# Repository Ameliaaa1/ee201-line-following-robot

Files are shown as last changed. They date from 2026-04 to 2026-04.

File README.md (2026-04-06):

# EE201 Line Following Robot

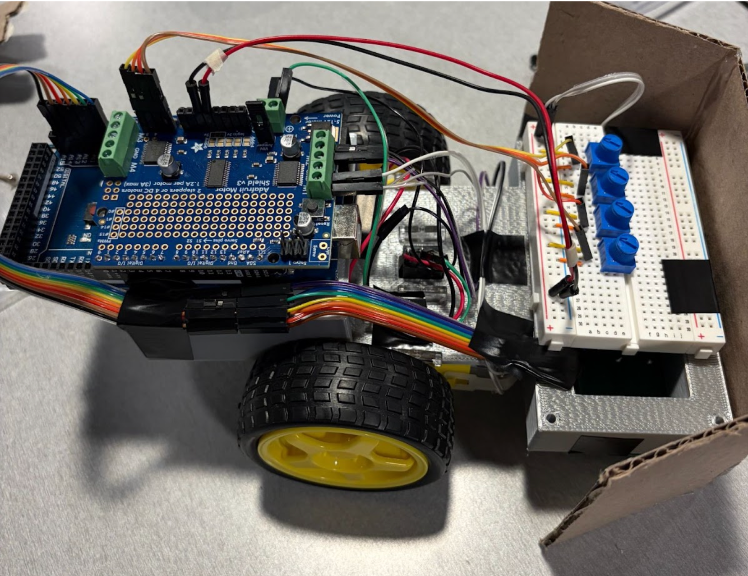
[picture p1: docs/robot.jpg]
Robot


A line-following robot built using Arduino, a custom sensor array, and PID control. This project was developed for EE 201 and focuses on integrating hardware design, embedded systems, and real-time control.

## Overview

This robot detects and follows a black line on a white surface using a photoresistor sensor array. Sensor readings are processed by an Arduino Mega, which adjusts motor speeds using a PID control algorithm to maintain alignment with the track.

## Features

- Arduino Mega + Adafruit Motor Shield
- 7-photoresistor sensor array with LED illumination
- Custom PCB design
- 3D-printed chassis
- Real-time PID control for line tracking
- Adjustable parameters using potentiometers

## Repository Structure

```text
/firmware/
  /arduino/
    /line_follower_pid/
      line_follower_pid.ino

/hardware/
  /pcb/
    sensor_array.kicad_pcb
    pcb-layout.pdf
    schematic.pdf
  /cad/
    chassis_main.stl
    arduino_breadboard_mount.stl
    prototype_part.stl

/docs/
  final-report.pdf

.gitignore
README.md
```
## Hardware Components

- Arduino Mega
- Adafruit Motor Shield
- DC motors and wheels
- Photoresistors
- LEDs
- Potentiometers
- Custom PCB
- 3D-printed chassis
- Battery power supply

## How It Works

1. Sensors detect light intensity differences between black and white surfaces.
2. The Arduino reads analog values from the sensor array.
3. A PID controller calculates the error relative to the line position.
4. Motor speeds are adjusted dynamically to correct the robot's direction.

## Results

The robot was able to follow the track with stable performance, especially at lower speeds. Environmental light and sensor distance significantly affected accuracy, which was mitigated using LEDs and a light shield.

## Future Improvements

- Improve chassis balance and structural rigidity
- Optimize PCB size and sensor placement
- Enhance performance on sharp turns
- Improve power stability

## Team Members

- Alexa Nassar
- Amelia Cai
- David Wang

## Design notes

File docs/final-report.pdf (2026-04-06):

# Drive-On-the-Line Project Report

Alexa Nassar, Amelia Cai, David Wang

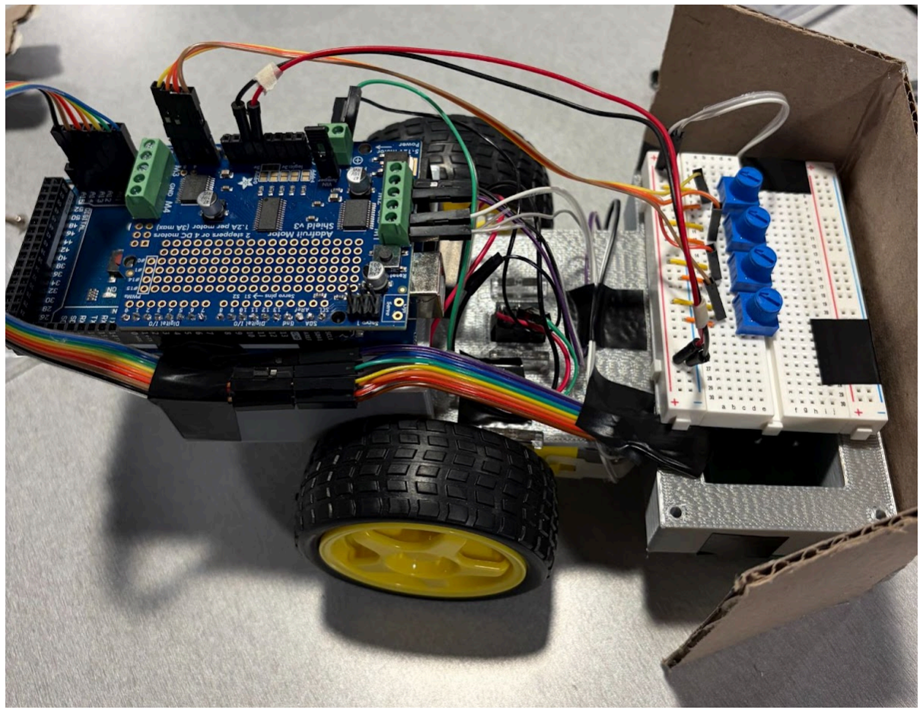
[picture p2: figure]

09-04-2026
EE 201: A Wi 26

## INTRODUCTION

This project focused on designing and building a small robot that can follow a black track rink. The robot uses a combination of LEDs and photoresistors to detect the difference between the black line and the white surrounding surface, allowing it to adjust its direction and stay on the path. The overall goal of this project was to apply the circuit design concepts learned in EE 201 to a real hardware system.

To build the robot, we first designed and tested the sensing and motor control circuits, then assembled the hardware and integrated it with the robot chassis. After several rounds of testing and adjustments, the final robot was able to follow the black track with stable movement. While we didn’t have the fastest robot, it was one of the smoothest and was able to complete the full track.

## PROCEDURE

The robot was built through several stages, including sensor setup, pcb and chassis design, motor integration, and system calibration.

First, potentiometers were connected to the Arduino Mega using a breadboard. These potentiometers acted as variable resistors and allowed real-time adjustment of parameters such as speed and PID coefficients. The Arduino code was used to read the potentiometer values through the analog inputs and display them in a serial monitor to ensure they had accurate readings.

Next, we designed and soldered a PCB to support the photoresistors used to detect the black track. Each photoresistor was paired with a resistor to form a voltage divider circuit, and the outputs were connected to the Arduino analog pins. LEDs were also used, with about one per photoresistor, to illuminate the ground and get a better read on what is a dark surface and what is light. Before proceeding, the sensors were tested on different surfaces to test their ability to clearly distinguish between black and white surfaces.

Then, we soldered the motor shield and attached it to the Arduino Mega. The DC motors were connected to the motor shield outputs, and the Adafruit motor shield library was installed in the Arduino IDE to enable motor control through software.

After testing all our components, we designed a custom chassis for the robot using CAD software and 3D printed the structure. The printed chassis was then assembled and used as the main frame of the robot. The custom chassis featured a box-like structure above the back wheel where the 9V battery and 6V battery pack sources are stored, and the Arduino is elevated upon. On the front end, our robot had a rectangular extension that extruded towards the floor. On this, we affixed our custom PCB to the bottom, facing the floor, to keep the LEDs and photoresistors as close to the surface as possible. On the upper side of this extrusion, in line with the surface of the chassis, we affixed our breadboard potentiometer circuit. In addition to our motors, wheels, switch, and wiring, we also created and attached a double-layered and black-lined light shield to the front of our robot with the purpose of limiting shadows and interference from other light sources. To help counterbalance our robot since it was too forward heavy, we also attached two 9V batteries to the back of our chassis for weight and stabilization.

Finally, all code components were integrated onto the robot, and the sensors were calibrated using a lot of trial and error to get the robot to move smoothly. A PID control algorithm was implemented to calculate the error between the robot's position and the desired line. In the calibration phase, the motor speeds were adjusted based on this error so the robot could continuously correct its direction and follow the black track.

## RESULTS

Challenge 1:

### 1. Twisting the potentiometers clockwise resulted in a decrease in values, while a

counterclockwise twist resulted in an increase.

### 2. Switching the polarity of the potentiometers (changing VCC to GND) would

provide opposite results when twisting the potentiometers.

Challenge 2:

### 1. The best distance for the sensors to properly differentiate between black and

white surfaces is within about 8 cm from the surface.

### 2. Surrounding light and shadows affect the readings significantly. Strong light

decreases the sensor readings, while shadows increase the readings.

### 3. The sensors are quite sensitive and are able to detect small changes in light

intensity.

### 4. If the sensors are not reading the difference in colors properly, the readings can

be improved by ensuring that the environmental brightness remains stable.

### 5. Adding an LED next to the photoresistors helps improve the readings because the

LED provides a consistent light source and reduces the effect of changes in environmental brightness.

### 6. Sensor accuracy can also be improved by surrounding the sensors with paper or a

small shield to further reduce the influence of the surrounding environment.

Challenge 3: ✓

Challenge 4: ✓

Challenge 5:

- All of our potentiometer knobs work. We are able to determine this by seeing their values increase, decrease and stay stable based on whether they are being twisted and in what direction on the serial monitor display.
- All of our photoresistors work and are able to sense the difference between a black and white surface. We are able to determine this by utilizing the serial monitor display and observing each one’s associated analog voltage value in real time. This allows us to actively test each photoresistor in different states to confirm that a brighter environment results in a higher voltage and a darker one results in a lower voltage.
- We know each motor is connected correctly and turns when it should because whenever our robot was given a turn command, it turned in the correct direction consistently for both left and right.
- At the end of challenge 5, our cart was driving forward and backward as needed.

Challenge 6:

- We implemented a light shield, a custom PCB, an extra 9 V battery, and used a custom chassis as hardware additions. The problems our hardware attempted to solve were interference from other light sources disrupting light/dark surface detection, space efficiency, and wire organization of the photoresistor circuit, insufficient power supply for the overall robot functionality, and improving overall robot structure and mobility, respectively.
- When implementing the hardware additions, our chassis needed extra counterbalance support since our weight wasn’t distributed evenly. We did this using a zip tie and extra batteries as back end weights to keep our robot from leaning forward and resting on our PCB. Additionally, we added a second layer to our light shield and lined the inside with black tape to improve its functionality in reducing light interference. In the end all our hardware implementations were successful in their given purpose, even if they were a little inefficient.

Challenge 7:

- After calibration, the photoresistors read between 80 and 90 when a black surface is placed in front of them. When a white surface is placed in front of them they read less than 15.

Challenge 8:

- The PID values we had checked off by our TA are 10.00, 0.00, and 8.00 respectively.

Challenge 9:

The robot worked well at low speed, but some errors occurred after running dozens of times due to the decrease of battery voltage.

If we redo the project, two major improvements would be:

### 1. Improve the modelling of the car body by shortening and strengthening the

structure for a better weight balance so as to avoid components touching the ground and creating friction that hampers the movement.

### 2. Shorten the PCB design, so that the light shield could be “tightened”. This would

help the sensing when facing the “short U-turns”, for the other parts of the parth would not be covered within the light shield and influence the reading.

## CONCLUSION

In this project, we designed and built a line-following robot capable of detecting and following a black track. Through creating custom additions, assembling the hardware, integrating sensors, and implementing PID control, we were able to create a system that could adjust its movement and stay on the track. The final robot was able to follow the line with relatively stable performance though slow speed.

This project helped us better understand how sensors, motor control, and feedback systems work together in a real system. We also gained experience troubleshooting hardware and tuning control parameters such as the PID coefficients. All of these are hands-on skills that are important for future work in electrical engineering, robotics, and embedded systems, particularly the ability to troubleshoot and adapt to unexpected challenges on a team project.

## REFERENCES

None :)

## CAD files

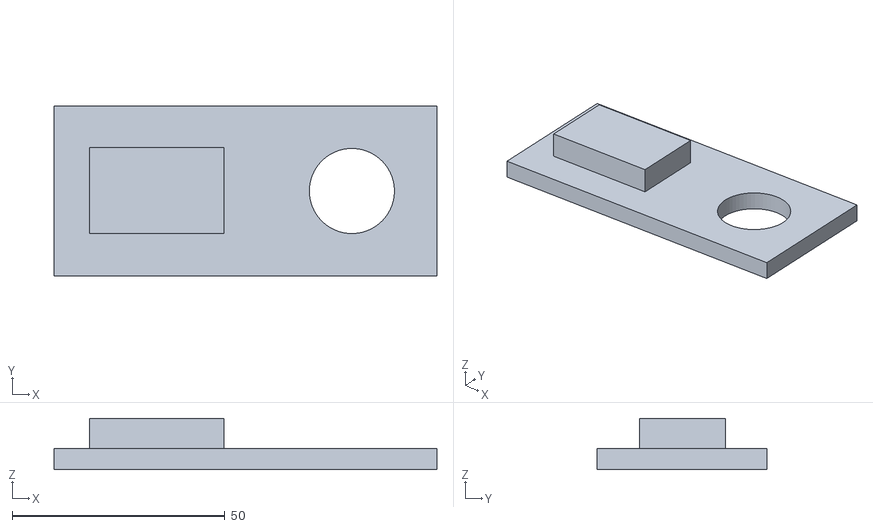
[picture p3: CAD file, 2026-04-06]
hardware/cad/chassis_main.stl
90.0 x 40.0 x 12.0

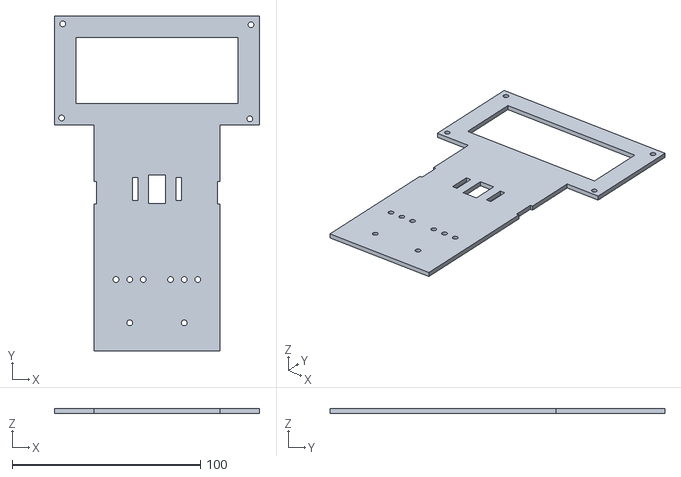
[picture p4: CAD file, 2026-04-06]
hardware/cad/prototype_part.stl
109.0 x 178.0 x 2.50

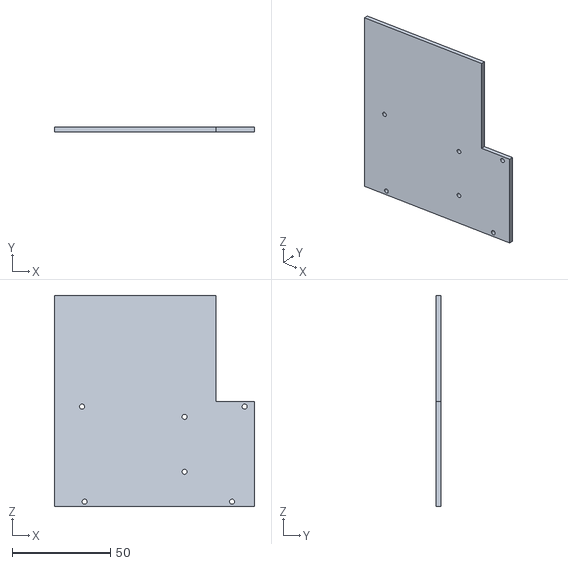
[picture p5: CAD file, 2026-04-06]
hardware/cad/arduino_breadboard_mount.stl
101.6 x 2.50 x 107.3

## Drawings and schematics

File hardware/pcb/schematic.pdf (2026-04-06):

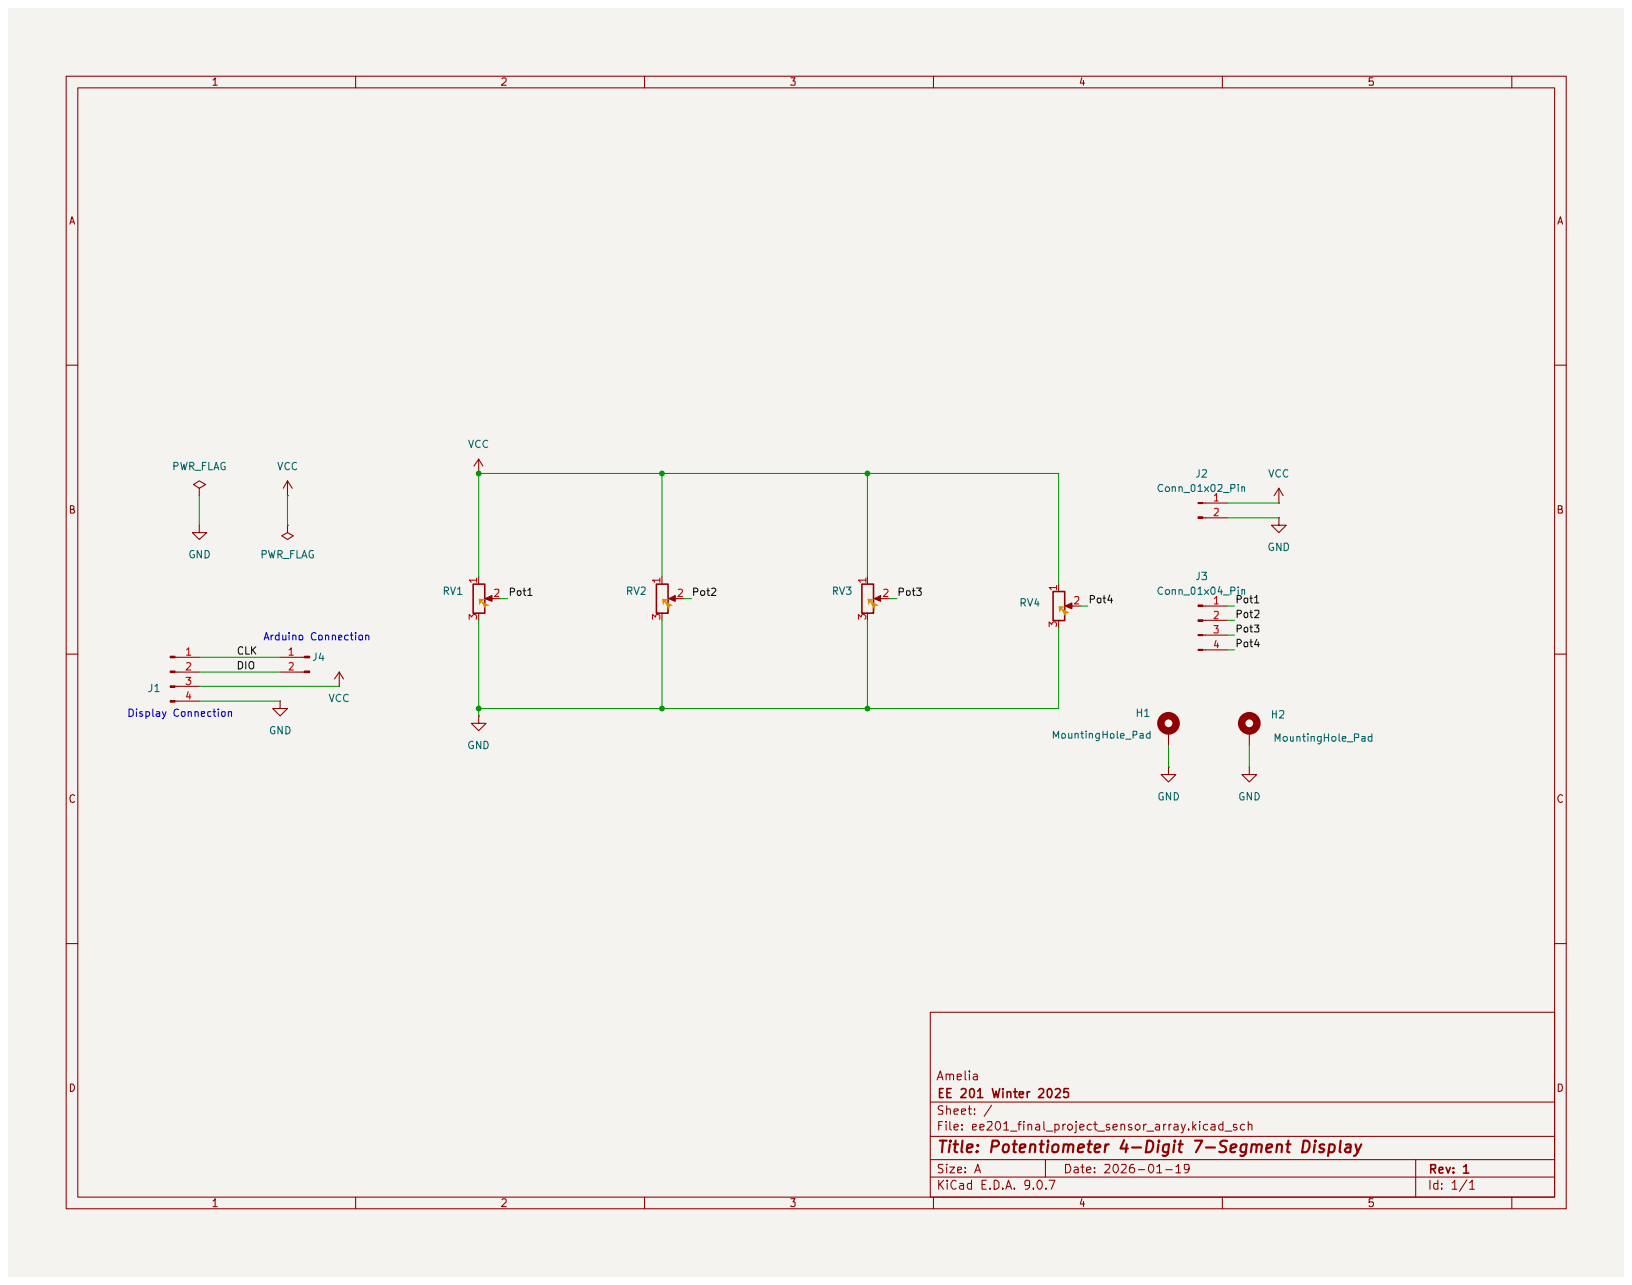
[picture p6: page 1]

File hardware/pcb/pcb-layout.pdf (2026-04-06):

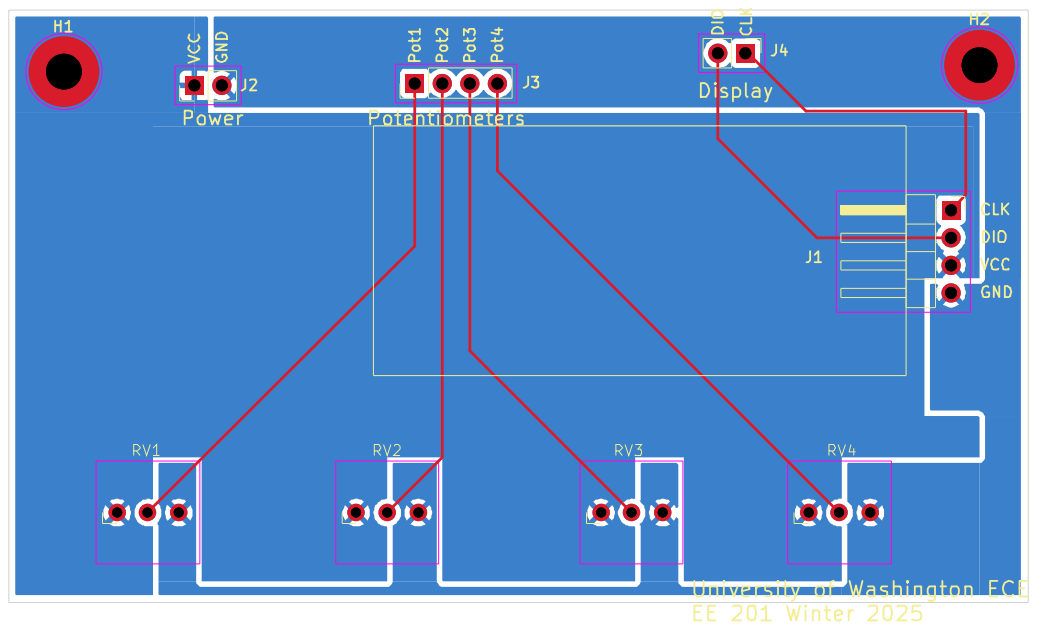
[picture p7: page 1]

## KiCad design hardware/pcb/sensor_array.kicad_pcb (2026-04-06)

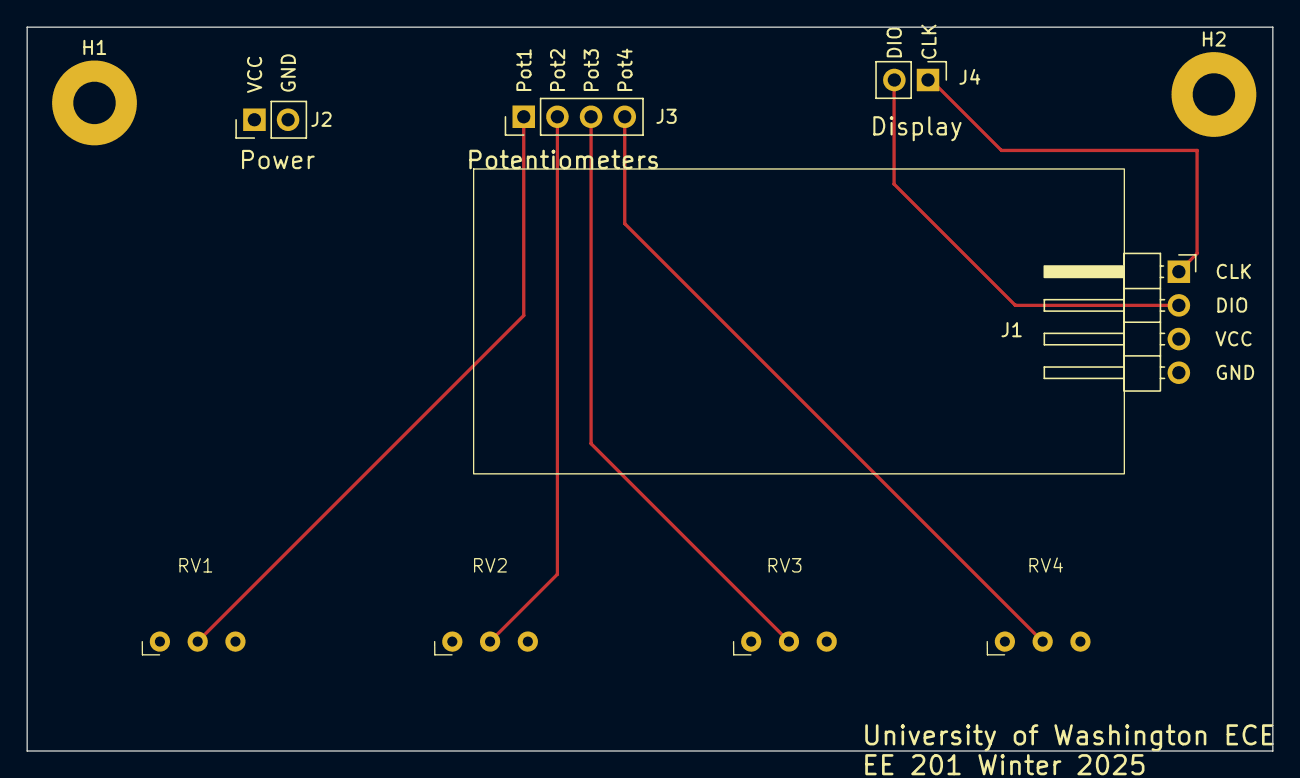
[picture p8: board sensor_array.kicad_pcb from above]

Board: 2 copper layers, 94.0 x 54.6 mm, 10 parts (0 on the bottom side), 8 nets.

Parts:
H1, H2: MountingHole_Pad; MountingHole_3.2mm_M3_Pad
J1: Display Connection; PinHeader_1x04_P2.54mm_Horizontal_left
J2: Conn_01x02_Pin; PinHeader_1x02_P2.54mm_Vertical
J3: Conn_01x04_Pin; PinHeader_1x04_P2.54mm_Vertical
J4: Arduino Connection; PinHeader_1x02_P2.54mm_Vertical
RV1, RV2, RV3, RV4: R_Potentiometer; Untitled

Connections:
/CLK: J1.1, J4.1
/DIO: J1.2, J4.2
/Pot1: J3.1, RV1.2
/Pot2: J3.2, RV2.2
/Pot3: J3.3, RV3.2
/Pot4: J3.4, RV4.2
GND: H1.1, H2.1, J1.4, J2.2, RV1.3, RV2.3, RV3.3, RV4.3
VCC: J1.3, J2.1, RV1.1, RV2.1, RV3.1, RV4.1

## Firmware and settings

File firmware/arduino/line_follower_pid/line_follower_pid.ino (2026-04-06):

/* ************************************************************************************************* */
// * ECE 201: Line Following Robot with PID * //
/* ************************************************************************************************* */
// This is code for your PID controlled line following robot. 
//
// Code Table of Contents
  // 1) Declare Variables - declares many variables as global variables so each variable can be accessed from every function
  // 2) Setup (Main) - runs once at beginning when you press button on arduino or motor drive or when you open serial monitor
  // 3) Loop (Main) - loops forever calling on a series of functions 
  // 4) Blink - blinks and LED
  // 5) Calibration - makes white = 0 and black = 100 (a few seconds to prep, a few seconds on white, a few seconds to move to black, a few seconds of black)
  // 6) Read Potentiometers - reads each potentiometer
  // 7) Run Motors - runs motors
  // 8) Read Photoresistors - reads each photoresistor
  // 9) Calculate Error - calculate error from photoresistor readings
  // 10) PID Turn - takes the error and implements PID control
  // 11) Print - used for debugging but can comment out when not debugging because it slows down program

// ************************************************************************************************* //
// Declare Variables

// Variables and Libaries for Motor
#include <Wire.h>
#include <Adafruit_MotorShield.h> // Must add libary - see MotorShield Manual
//https://cdn-learn.adafruit.com/downloads/pdf/adafruit-motor-shield-v2-for-arduino.pdf

Adafruit_MotorShield AFMS = Adafruit_MotorShield();
// Motors can be switched here (1) <--> (2)
Adafruit_DCMotor *Motor1 = AFMS.getMotor(1); // left motor
Adafruit_DCMotor *Motor2 = AFMS.getMotor(2); // right motor
  
// Set Initial Speed of Motors (CAN BE EDITED BY USER)
// TODO: Replace "___", and set the default motor speeds to an integer between 0 and 255.
//  the defualt motor speed is how fast the cart will move with no inputs. this can be
//  thought of as how fast should the cart be going when travelling in a straight line.
//  theoretical max. is 255, but the motors will likely overdraw power and cause the Arduino to shut off. 
//  motors likely need a minimum speed of at least 30 to move the cart.
//  a good starting speed is roughly 50-60. motor speeds are separated incase one motor turns faster than the other.  
const int M1Sp = 50; 
const int M2Sp = 50;

// Variables for Potentiometer
// TODO: Replace "___", and assign the pin number connected to the Arduino
const int S_pin = A0; //speed control
const int P_pin = A1; //proportional control
const int I_pin = A2; //integral control
const int D_pin = A3; //derivative control

// User set SPID values
// TODO: Replace "___", and assign an integer value for the MAX value of S, P, I, and D.
//  The on-cart potentiometers are used to determine the actual values of S, P, I, and D. 
//  Note: These values will likely need to be experimentally determined
const float speed       = 40;
const float proportion  = 20;
const float integral    = 0;
const float derivative  = 10;

const int numMeas = 40; // TODO: Replace "___", and assign number of calibration measurements
                         //   setting numMeas to 40 as in code 10.4 is recommended

// Initialize SPID values to zero
int SpRead = 0; //Speed Increase 
int kPRead = 0; //proportional gain
int kIRead = 0; //integral gain
int kDRead = 0; //derivative gain
  
// Variables for Light Sensors (arrays are used to simplify the code):
//  these are variables that have multiple elements to each variable name.
//  LDR_Pin holds 7 values of the LDR pin connection to the Arduino
// TODO: Replace "___", and assign the pin number for each LDR connected to the Arduino.
//  reference 10.2 potentiometer code if necessarry
int LDR_Pin[7] = {A8,
                  A9,
                  A10,
                  A11,
                  A12,
                  A13,
                  A14}; 
int LDR[7]; // this is an empty array that will hold the readings from our potentiometers

// TODO: Replace "___", and assign the pin number connected to the Arduino.
//  it is recommended to use the built-in LED connected to pin 13, but can change 
//  to another digital pin and connect external LED to be more easily seen
int led_Pin = 14; 

// Calibration Variables
//  Complete understanding of the calibration process is not required 
float Mn[7]; // array containing minimum read values of every potentiometer
float Mx[7]; // array containing maximum read values of every potentiometer
float LDRf[7] = {0.,0.,0.,0.,0.,0.,0.}; // initialize the LDR read values to float zero

int MxRead; // maximum read value by any potentiometer
int MxIndex; // index (location in array) of max read value
float AveRead; // average read value of potentiometer
int CriteriaForMax; // value to determine whether a read value is a max
float WeightedAve; // weighted average after calibration
  
// Error calculation variables
int im0, im1, im2; 
  
// Motor control variables
int M1SpeedtoMotor, M2SpeedtoMotor; // actual speeds motor will be rotating at
int Turn; // which direction and how sharply should the cart turn
int M1P = 0, M2P = 0; // proportion control for motors 1 and 2 respectively
float error; // current error
int lasterror = 0; // previous error
int sumerror = 0; // sum of total errors
float kP, kI, kD; // final values of P, I, and D used in control
 
// ************************************************************************************************* //
// setup - runs once
void setup() {
  Serial.begin(9600); // TODO: Replace "___", and input the baud rate for serial communication
  AFMS.begin(); // initialize the motor

  pinMode(led_Pin, OUTPUT); // TODO: Replace "___", and set the led_pin to be an output
  
  Calibrate(); // Calibrate black and white sensing
  
  ReadPotentiometers(); // Read potentiometer values (Sp, P, I, & D)
  
  delay(2000); // Delay to ensure cart is properly placed before moving
  
  RunMotors(); // Starts motors straight forward depending on Sp (Speed from potentiometer) and M1Sp/M2Sp (Nominal values)
 
} // end setup()

// ************************************************************************************************* //
// loop - runs/loops forever
void loop() {
  // Note: some functions are only helpful for debugging and can be commented out once functionality is ensured
 
  ReadPotentiometers(); // Only if you want to see Potentiometers working in set up as you run the line following
  
  ReadPhotoResistors(); // Read photoresistors and map to 0-100 based on calibration
  
  CalcError();
  
  PID_Turn(); // PID Control and Output to motors to turn
  RunMotors(); // Uses info from
  
  Print(); // Print values to serial monitor //currently commented out but could be good for debugging =)
 
} // end loop()

// ************************************************************************************************* //
// function to quickly blink an LED
void fastBlink() {
  digitalWrite(led_Pin, 1); // TODO: Replace "___", and turn on the LED
  delay(100); // wait for 100 milliseconds

  digitalWrite(led_Pin, 0); // TODO: Replace "___", and turn off the LED
  delay(100); // wait for 100 milliseconds
} // end fastBlink()

// ************************************************************************************************* //
// function to slowly blink an LED
void slowBlink() {
  digitalWrite(led_Pin, 1); // TODO: Replace "___", and turn on the LED
  delay(100); // wait for 100 milliseconds

  digitalWrite(led_Pin, 0); // TODO: Replace "___", and turn off the LED
  delay(900); // wait for 900 milliseconds
} // end slowBlink()

// ************************************************************************************************* //
// function to calibrate
void Calibrate() { 
  // wait to make sure cart is in position with sensors over a white (light) surface
  for (int calii = 0; calii < 4; calii++) { // wait four blinks for the cart to be positioned
    slowBlink(); // blink the indicator LED
  }
  
  // Calibration
  // White Calibration
  for (int calii = 0; calii < numMeas; calii++) { // TODO: Replace "___", and repeat the section of code
                                                    //  for the number of calibration measurements desired

    fastBlink(); // blink the indicator LED

    for (int ci = 0; ci < 7; ci++) { // TODO: Replace "___", and loop over all of the LDRs
      LDRf[ci] = LDRf[ci] + (float) analogRead(LDR_Pin[ci]); // keep track of the sum of each LDR's readings
      delay(2); 
    } 
  } 
    
  // Find average of each LDR's read values
  for (int cm = 0; cm < 7; cm++) { // TODO: Replace "___", and loop over all of the LDRs
    Mn[cm] = round(LDRf[cm] / (float)numMeas); // take average of each LDR's readings
    LDRf[cm] = 0.; // reset the array holding the sum of the LDR's readings
  }
 
 // Wait to move from White to Black Surface
  for (int calii = 0; calii < 4; calii++) { // wait ten blinks for the cart to be repositioned
    slowBlink();
  }
 
  // Black Calibration
  for (int calii = 0; calii < numMeas; calii++) { // TODO: Replace "___", and repeat the section of code
                                                    //  for the number of calibration measurements desired

    fastBlink(); // blink the indicator LED

    for (int ci = 0; ci < 7; ci++) { // TODO: Replace "___", and loop over all of the LDRs
      LDRf[ci] = LDRf[ci] + (float) analogRead(LDR_Pin[ci]); // keep track of the sum of each LDR's readings
      delay(2); 
    } 
  }  
  
  // Find average of each LDR's read values
  for (int cm = 0; cm < 7; cm++) { // TODO: Replace "___", and loop over all of the LDRs
    Mx[cm] = round(LDRf[cm] / (float)numMeas); // take average of each LDR's readings
    LDRf[cm] = 0.; // reset the array holding the sum of the LDR's readings
  }
} // end Calibrate()

// ************************************************************************************************* //
// function to read and map values from potentiometers
void ReadPotentiometers() {
  SpRead = map(analogRead(S_pin), 0, 1023, 0, speed);
  kPRead = map(analogRead(P_pin), 0, 1023, 0, proportion);
  kIRead = map(analogRead(I_pin), 0, 1023, 0, integral);
  kDRead = map(analogRead(D_pin), 0, 1023, 0, derivative);
} // end ReadPotentiometers()
 
// ************************************************************************************************* //
// function to start motors using nominal speed + speed addition from potentiometer
void RunMotors() { 
  M1SpeedtoMotor = min(M1Sp + SpRead + M1P, 255); // limits speed to 255 
  M2SpeedtoMotor = min(M2Sp + SpRead + M2P, 255); // remember M1Sp & M2Sp is defined at beginning of code (default 60)
  
  Motor1->setSpeed(abs(M1SpeedtoMotor)); 
  Motor2->setSpeed(abs(M2SpeedtoMotor));
  
  // Motor 1 control
  if (M1SpeedtoMotor > 0) {
    Motor1->run(FORWARD);
  } else { // < 0
    Motor1->run(BACKWARD);
  }

  // Motor 2 control
  if (M2SpeedtoMotor > 0) {
    Motor2->run(FORWARD);
  } else { // < 0 
    Motor2->run(BACKWARD);
  }
} // end RunMotors()

// ************************************************************************************************* //
// function to read photo resistors, map from 0 to 100, and find darkest photo resitor (MxIndex)
void ReadPhotoResistors() {
  for (int Li = 0; Li < 7; Li++) { // TODO: Replace "___", and loop over all of the LDRs
    LDR[Li] = map(analogRead(LDR_Pin[Li]), Mn[Li], Mx[Li], 0, 100);
    delay(2); 
  }
} // end ReadPhotoResistors()

// ************************************************************************************************* //
// Calculate error from photoresistor readings
//  Do not worry about understanding or completing this function
void CalcError() {
  MxRead = -99; // initialize max read to an impossible value to ensure initialization does not impact functionality
  AveRead = 0.0; // initialize the average read

  for (int i = 0; i < 7; i = i + 1) { // loop over all of the LDRs
    if (MxRead < LDR[i]) { // if LDR value is greater than current max
      MxRead = LDR[i]; // set max equal to LDR value
      MxIndex = -1 * (i-3);
      im1 = (float)i;
    }
    AveRead = AveRead + (float)LDR[i]/7.;
  } 
  CriteriaForMax = 2; // max should be at least twice as big as the other values 
  if (MxRead > CriteriaForMax*AveRead) {
    if (im1 != 0 && im1 != 6) {
      im0 = im1 - 1;
      im2 = im1 + 1;
      WeightedAve = ((float)(LDR[im0] * im0 + LDR[im1]*im1 + LDR[im2] * im2))/((float)(LDR[im0] + LDR[im1] + LDR[im2]));
      error = -1 * (WeightedAve - 3);
    }
    else if (im1 == 0) {
      im2 = im1 + 1;
      WeightedAve = ((float)(LDR[im1]*im1 + LDR[im2]*im2))/((float)(LDR[im1]+LDR[im2]));
      error = -1 * (WeightedAve - 3);
    }
    else if (im1 == 6) {
      im0 = im1 - 1;
      WeightedAve = ((float)(LDR[im0]*im0 + LDR[im1]*im1))/((float)(LDR[im0]+LDR[im1]));
      error = -1 * (WeightedAve - 3);
    } 
  } 

  if (isnan(error)) {
    error = lasterror;
  } else {
    error = error;
  }
} // end CalcError()

// ************************************************************************************************* //
// function to make a turn (a basic P controller)
void PID_Turn() {
  // Read values are scaled PID constants from potentiometers
  kP = (float)kPRead; 
  kI = (float)kIRead; 
  kD = (float)kDRead;

  // error holds values from -3 to 3
  Turn = error * kP + sumerror * kI + (error - lasterror) * kD; //PID!!!!!
  
  sumerror = sumerror + error;

  // prevents integrator wind-up
  if (sumerror > 5) {
    sumerror = 5; 
  } else if (sumerror < -5) {
    sumerror = -5;
  }
  
  lasterror = error;
  
  // One motor becomes slower and the other faster, to "turn"
  if (Turn < 0) { // turn in direction of M2
    M1P = Turn; 
    M2P = -Turn;
  } else if (Turn > 0) { // turn in direction of M1
    M1P = Turn; 
    M2P = -Turn;
  } else { // continue in straight line
    M1P = 0; 
    M2P = 0;
  } 
} // end PID_Turn()

// ************************************************************************************************* //
// function to print values of interest
void Print() {
  Serial.print(Turn); Serial.print(" ");
  Serial.print(error); Serial.print(" ");
  Serial.print(sumerror); Serial.print(" ");
  Serial.print(lasterror); Serial.print(" ");
  
  Serial.print("   |   "); // create a visual divider
  
  Serial.print(SpRead); Serial.print(" "); // Initial Speed addition from potentiometer
  Serial.print(kP); Serial.print(" "); // PID values from potentiometers after scaling 
  Serial.print(kI); Serial.print(" ");
  Serial.print(kD); Serial.print(" ");

  Serial.print("   |   "); // create a visual divider
  
  Serial.print(LDR[0]); Serial.print(" "); // Each photo resistor value is shown
  Serial.print(LDR[1]); Serial.print(" ");
  Serial.print(LDR[2]); Serial.print(" ");
  Serial.print(LDR[3]); Serial.print(" ");
  Serial.print(LDR[4]); Serial.print(" ");
  Serial.print(LDR[5]); Serial.print(" ");
  Serial.print(LDR[6]); Serial.print(" "); 

  Serial.print("   |   "); // create a visual divider
  
  Serial.print(MxRead); Serial.print(" "); // the maximum value from the photo resistors is shown again
  Serial.print(MxIndex);Serial.print(" "); // this is the index of that maximum (0 through 6) (aka which element in LDR)
  Serial.print(error); Serial.print(" "); // this will show the calculated error (-3 through 3) 

  Serial.print("   |   "); // create a visual divider
  
  Serial.print(M1SpeedtoMotor); Serial.print(" "); // This prints the arduino output to each motor so you can see what the values (0-255)
  Serial.println(M2SpeedtoMotor); // that are sent to the motors would be without actually needing to power/run the motors
  
  delay(200); //just here to slow down the output for easier reading if wanted 
                 // ensure delay is commented when actually running your robot or this will slow down sampling too much
                 // and prevent the cart from functioning well
} // end Print()

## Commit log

2026-04-06 Add Arduino firmware
2026-04-06 Add PCB design file
    [sensor_array.kicad_pcb]
2026-04-06 Add PCB layout PDF
